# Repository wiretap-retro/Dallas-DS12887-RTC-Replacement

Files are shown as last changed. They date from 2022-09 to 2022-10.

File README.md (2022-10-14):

# Dallas DS12887 RTC Replacement
A simple Dallas DS12887 replacement board with enable/disable function and ext_batt header.

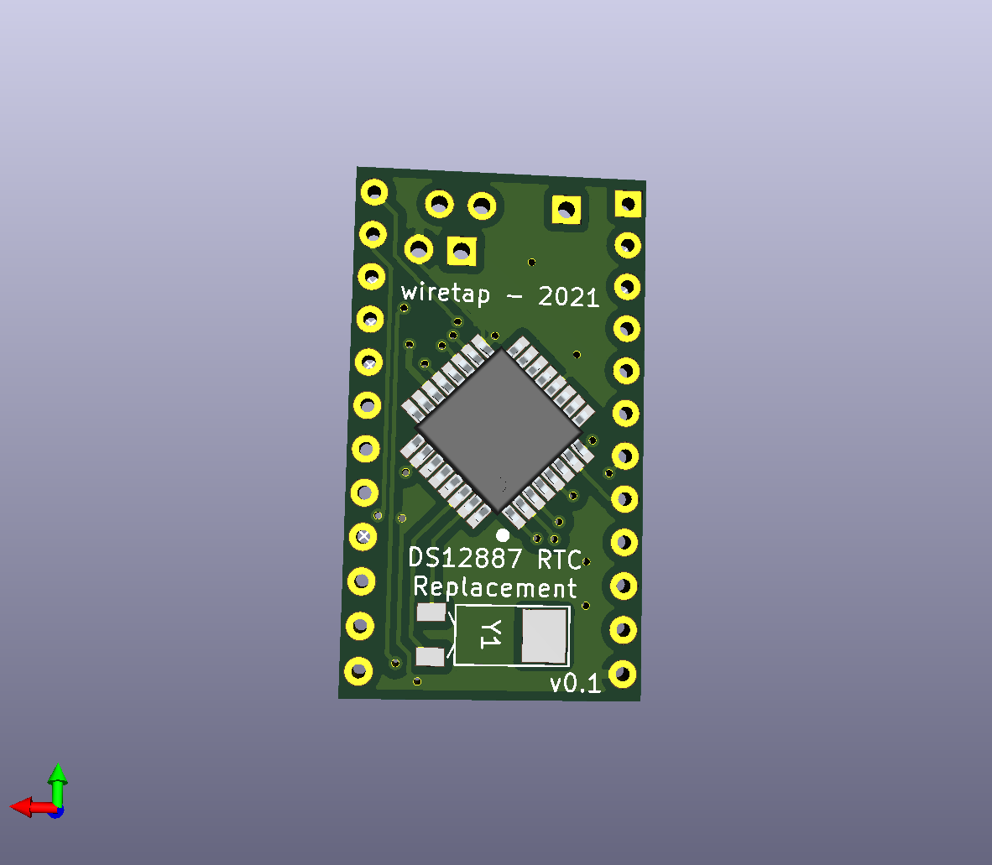
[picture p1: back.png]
back

\
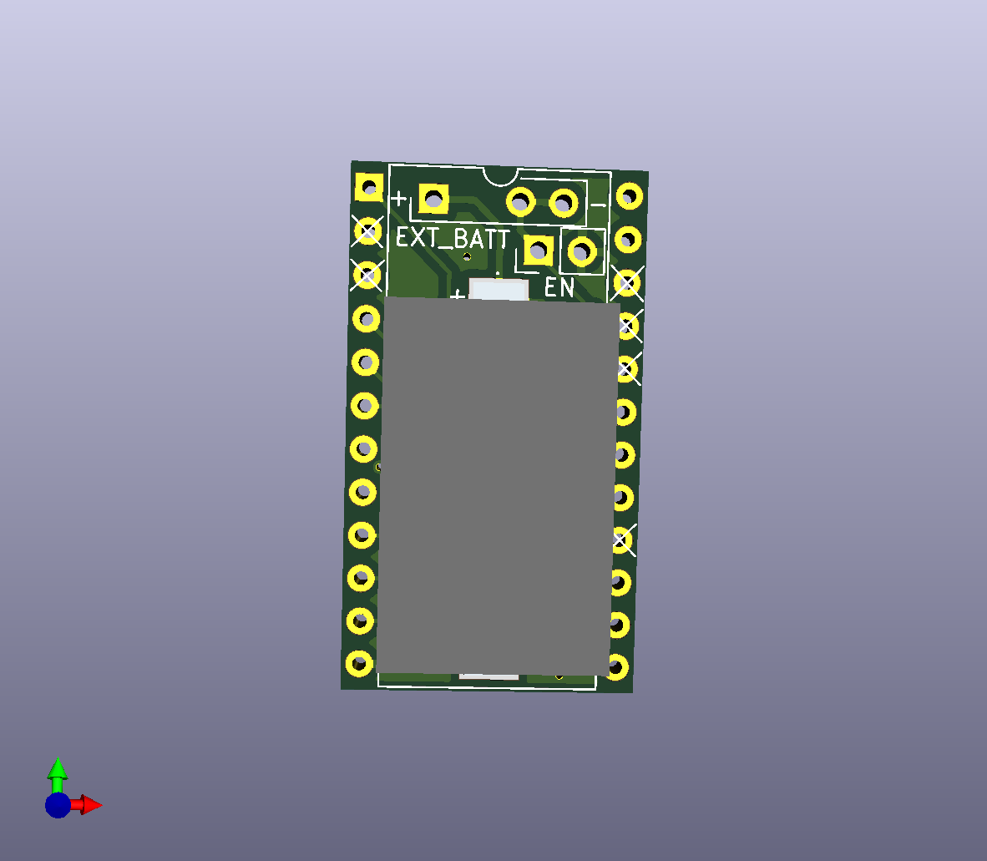
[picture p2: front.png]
front


## Info
This Dallas DS12887 replacement utilizes a DS12885T+ TQFP-32 chip and a CR1220 battery holder. There is an enable/disable pin for you to save battery while the computer is in storage, and there's also an EXT_BATT header for hooking up an external battery holder if you don't want to use a CR1220 battery.

## Compatibility
Compatible with DS12887, DS1285 and DS1287 RTC's. Check datasheet for additional info: https://www.mouser.com/datasheet/2/256/DS12885-DS12C887A-1512672.pdf
\
\
Dallas -85 model numbers are just the bare RTC chip. Dallas -87 model numbers are the chip in an encapsulated package with the battery and crystal. Example: The Dallas DS14285 with a crystal and battery is the same thing as a DS14287 (compatible with the DS1287, which is actually just a DS1285 with a crystal and battery).

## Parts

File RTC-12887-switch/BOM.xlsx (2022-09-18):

Reference | Value | Footprint | Description | Manufacturer Name | Manufacturer Part Number | Mouser Part Number
Y1 | Crystal | 2-lead cylinder | 32.768 kHz Crystal | ECS | ECS-.327-6-13FLX-C-TR | 520-27-6-13FLX-C-TR
U1 | SMTU1220-LF | CR1220 Battery Holder | Coin Cell Battery Holders SFC MNT FOR CR1220 | RENATA | SMTU1220-LF | 614-SMTU1220-LF
IC1 | DS12885T+ | TQFP-32 | Real Time Clock RTC | Maxim Integrated | DS12885T+ | 700-DS12885T
Pin Headers (use a 1-row 2.54mm breakaway pin header)
Two 1x12 for the DS12887 holes that go into the motherboard (remove pins with "x" on the PCB)
One 1x2 for the enable pin (this enable pin will cut off battery power for long term storage)
One 1x4 for the EXT_BATT header (optional if you want to use that header with an external battery pack)
Jumpers (2.54mm spacing)
One 1x2 jumper for the enable jumper. Optionally, you can solder the two pads together if you don't want to use the enable/disable power feature.

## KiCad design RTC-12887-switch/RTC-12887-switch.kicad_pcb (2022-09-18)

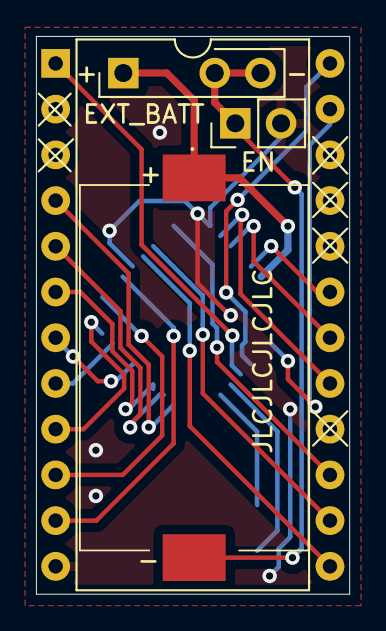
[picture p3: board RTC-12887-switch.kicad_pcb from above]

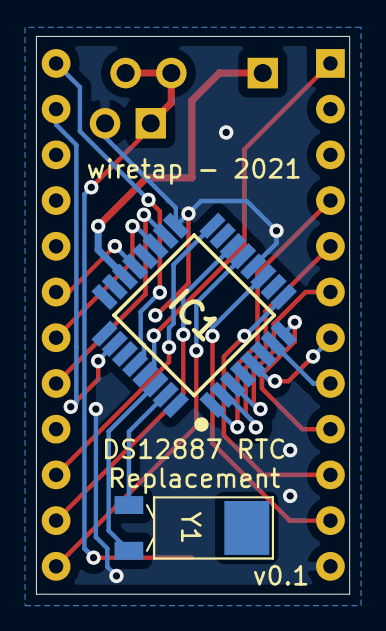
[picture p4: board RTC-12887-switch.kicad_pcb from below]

Board: 2 copper layers, 17.4 x 31.0 mm, 6 parts (2 on the bottom side), 22 nets.

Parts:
EN: PWR; PinHeader_1x02_P2.54mm_Vertical
IC1: DS12885T+; QFP80P900X900X120-32N
IC2: DS12887+; DIP-24_W15.24mm
J1: EXT_BATT
U1: SMTU1220-LF; SMTU1225LF
Y1: Crystal; Crystal_SMD_FrontierElectronics_FM206

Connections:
/AD0: IC1.1, IC2.4
/AD1: IC1.2, IC2.5
/AD2: IC1.3, IC2.6
/AD3: IC1.5, IC2.7
/AD4: IC1.7, IC2.8
/AD5: IC1.8, IC2.9
/AD6: IC1.9, IC2.10
/AD7: IC1.11, IC2.11
/AS: IC1.14, IC2.14
/BC: IC1.22, J1.1, U1.1
/COM: EN.1, J1.3, J1.4, U1.2
/CS: IC1.13, IC2.13
/DS: IC1.18, IC2.17
/IRQ: IC1.21, IC2.19
/MOT: IC1.29, IC2.1
/RESET: IC1.19, IC2.18
/RW: IC1.16, IC2.15
/SQW: IC1.26, IC2.23
/VCC: IC1.28, IC2.24
/X1: IC1.30, Y1.1
/X2: IC1.31, Y1.2
GND: EN.2, IC1.12, IC1.17, IC2.12
